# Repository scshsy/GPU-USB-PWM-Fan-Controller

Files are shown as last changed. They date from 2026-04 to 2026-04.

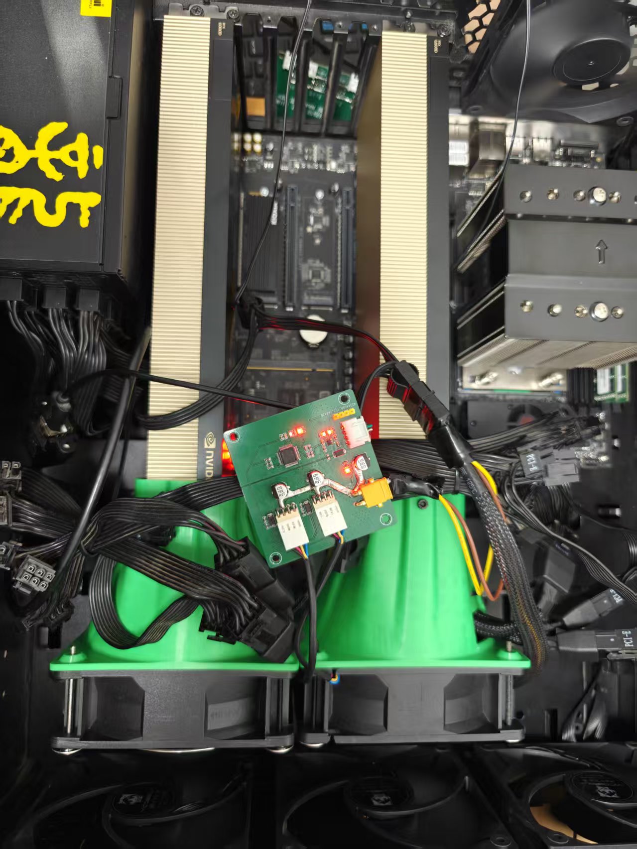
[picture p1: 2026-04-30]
RTX6000D散热方案/img3.jpg

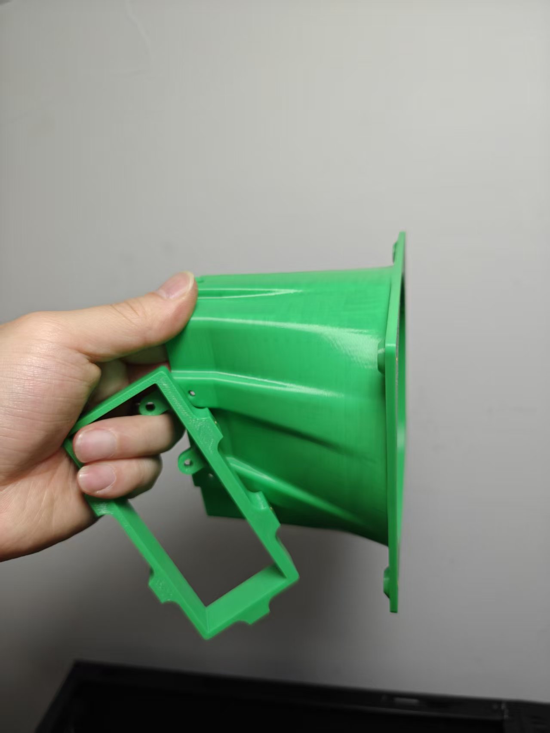
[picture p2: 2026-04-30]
RTX6000D散热方案/img.jpg

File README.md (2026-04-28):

# GPU USB PWM Fan Controller（GPU 温控 USB PWM 风扇控制器）

> **简易版（上手用这一页）**。详细版请看 `docs/PROJECT_GUIDE.md`。

## 项目做什么

- STM32G0B1 固件控制 **2 路 4-pin 风扇**：25 kHz PWM 调速 + TACH 测速
- USB CDC（虚拟串口）文本协议：主机下发占空比、回读 RPM、查询状态
- **Fail-safe 安全策略**：USB 未枚举 / 主机失联 / 脚本崩溃 → 自动回安全档
- PC 端脚本：读取 `nvidia-smi` 的 **多卡温度**，取最高温 → 计算 duty → 下发 → 回读 RPM

## 快速开始（Windows / 开发机）

### 1) 编译

```bash
pio run -e nucleo_g0b1re
```

产物：`.pio/build/nucleo_g0b1re/firmware.bin`

### 2) 一键 DFU 刷写（板子在跑应用时）

```bash
python tools/dfu_upload.py .pio/build/nucleo_g0b1re/firmware.bin
```

> dfu-util 的 exit code 74 已在脚本中兼容（STM32 ROM `:leave` 已知“假错误”）。

### 3) 串口验证（协议）

```bash
pio device monitor -b 115200
```

在 monitor 里输入：

- `get status`：看当前 duty/rpm/usb/src/wd/fault
- `get rpm`：看两路 RPM
- `set fan 1 30` + `set fan 2 30`：下发 duty
- `kick`：喂主机 watchdog（不改变 duty）
- `dfu`：进入 ROM DFU（供 `dfu_upload.py` 使用）

## 自动温控（GPU 温度→风速）

### 1) 运行（真实下发）

```bash
python tools/fan_daemon.py --port COM4
```

### 2) 配置文件（温度→duty 曲线）

默认读取：`/etc/pwm_fan/config`（Ubuntu/Linux；手动运行与 systemd 共用同一份）

配置样例见：`docs/PROJECT_GUIDE.md`（推荐用 `[curve] points = 40:30, 55:50, ...` 这种分段线性点）

### 3) 只演算不下发（dry-run）

```bash
python tools/fan_daemon.py --dry-run
```

## Ubuntu Server 一键部署（无需源码）

```bash
curl -fsSL https://raw.githubusercontent.com/scshsy/GPU-USB-PWM-Fan-Controller/main/tools/deploy.sh | sudo bash
```

脚本会自动：安装系统依赖 → 从 GitHub 拉取代码 → 安装程序和配置文件 → 启动 systemd 服务。

已有源码时也可手动执行：
```bash
sudo bash tools/deploy.sh
```

常用命令：
```bash
sudo systemctl status pwm-fan.service
sudo journalctl -u pwm-fan -f
pwm-fan-rpm
pwm-fan-status
pwm-fan-help
```

系统命令：
- `pwm-fan-rpm`
- `pwm-fan-status`
- `pwm-fan-help`

## 硬件源文件（开源入口）

- 嘉立创EDA 专业版工程（**原理图 + PCB**）：`hardware/GPU USB PWM Fan Controller.epro`

## 关键文档入口

- USB CDC（详细踩坑/架构）：`docs/USB_CDC_GUIDE.md`
- USB DFU（一页纸）：`docs/USB_DFU.md`
- USB DFU（详细版）：`docs/USB_DFU_GUIDE.md`
- 风扇控制（协议/安全策略/接线）：`docs/FAN_CONTROL.md`
- 项目总文档（详细版）：`docs/PROJECT_GUIDE.md`

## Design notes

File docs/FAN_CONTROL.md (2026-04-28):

# 风扇控制（GPU USB PWM Fan Controller）

## 1. 硬件接线与约束

### 1.1 4-pin 风扇线序（常见配色）

> 不同厂商可能配色不同，但行业常见是：

- 黑：GND
- 黄：+12V
- 绿：PWM（控制输入，25 kHz）
- 蓝：TACH（转速输出，开漏/开集电极）

### 1.2 本控制板 IO（已定板）

- **硬件源文件（嘉立创EDA 专业版，原理图 + PCB）**
  - `hardware/GPU USB PWM Fan Controller.epro`

- **PWM 输出（推挽，25 kHz）**
  - PA8 → TIM1_CH1 → FAN1_PWM
  - PA9 → TIM1_CH2 → FAN2_PWM
- **TACH 输入（外部 4.7K 上拉到 3.3V + RC 滤波 → MCU 浮空输入）**
  - PA6 → TIM3_CH1 → FAN1_TACH
  - PA7 → TIM3_CH2 → FAN2_TACH
- **风扇脉冲规格**
  - 每转 2 个脉冲（2 PPR）

### 1.3 供电说明（重要）

- **USB 与风扇 12V 供电无关**：风扇的 +12V 由外部 12V 电源提供。
- **必须共地**：外部 12V 电源的 GND 与本板 GND 必须相连（共地），否则 PWM/TACH 参考电平漂移会导致失控或测速异常。

---

## 2. CDC 文本协议（行协议）

### 2.1 基本规则

- 传输通道：USB CDC 虚拟串口（VID `0483` PID `5740`）
- 行结束：`\r\n` 或 `\n`
- 命令大小写不敏感
- 应答一行一条，末尾带 `\r\n`

### 2.2 命令表

| 命令 | 应答 | 说明 |
|---|---|---|
| `set fan <ch> <pct>` | `ok` / `err <reason>` | `ch` ∈ {1,2}，`pct` ∈ [0,100]；合法命令会刷新 host watchdog |
| `kick` | `ok` | 仅喂狗，不改变 duty |
| `get rpm` | `rpm 1=<n> 2=<m>` | 返回两路 RPM（停转/超时视为 0） |
| `get status` | `duty=<a>,<b> rpm=<n>,<m> usb=<0/1> src=<host|safe|default|override> wd=<ms_left> fault=0x<bits>` | 综合状态 |
| `?` |（CRS 诊断行）| 见 `docs/USB_CDC_GUIDE.md` |
| `dfu` | `entering DFU` 后复位 | 进入 ROM DFU（见 `docs/USB_DFU.md`） |

> `fault` bit（当前实现）：
> - bit0: USB 未枚举（非 CONFIGURED）
> - bit1: host watchdog 超时

---

## 3. 固件安全策略（Fail-safe）

### 3.1 两个常量（已分离）

- **上电默认档**：`FAN_DEFAULT_DUTY_PCT = 80%`
- **安全档**：`FAN_SAFE_DUTY_PCT = 80%`

未来可以独立调这两个值（例如默认 80%，失联档 100%）。

### 3.2 触发条件

1. **上电/复位**：先进入默认档（80%）
2. **USB 未枚举**：强制安全档（80%）
3. **主机失联 watchdog**：任意合法 `set fan` / `kick` 会刷新时间戳；超过 3000ms 未刷新 → 强制安全档（80%）

### 3.3 状态机（ASCII）

```
                +------------------+
   reset/power  |     DEFAULT      |
   ------------>+ duty=DEFAULT(80) |
                +------------------+
                        |
                        | (USB configured) + first host msg
                        v
                +------------------+
                |       HOST       |
                | duty=host target |
                +------------------+
                   |          |
     wd timeout     |          | USB not configured
  (>3000ms no kick) |          |
                   v          v
                +------------------+
                |       SAFE       |
                | duty=SAFE(80)    |
                +------------------+
                        ^
                        |
                        | (USB configured) + host msg resumes
                        |

  OVERRIDE：调试/应急覆盖（优先级最高），覆盖上面所有状态
```

---

## 4. PC 端温控脚本（`tools/fan_daemon.py`）

### 4.1 设计要点

- **多卡规则**：枚举所有 GPU，取温度最大值作为决策温度
- **双通道同步**：每轮都发 `set fan 1 X` + `set fan 2 X`
- **滞回**：3°C，避免频繁上下跳
- **最低保活档**：任何时候 duty < 30% 会被抬到 30%
- **失败兜底**：连续 3 次读不到温度时先改为 75%；再持续失败会退出，让板载 watchdog 接管安全档

### 4.2 用法

```bash
python tools/fan_daemon.py
```

常用参数：

```bash
python tools/fan_daemon.py --port COM5 --interval 1.0
python tools/fan_daemon.py --gpu-filter "RTX|A100" --curve preset:aggressive
python tools/fan_daemon.py --dry-run
```

---

## 5. 多卡日志样例（1/2/4 卡）

### 5.1 1 卡

```
2026-04-28 22:00:00 gpus=[0:52C] max=52C duty=44% rpm 1=12345 2=12340
```

### 5.2 2 卡（取最高温）

```
2026-04-28 22:00:01 gpus=[0:48C 1:76C] max=76C duty=90% rpm 1=17800 2=17720
```

### 5.3 4 卡（任意一张卡热就拉高风量）

```
2026-04-28 22:00:02 gpus=[0:41C 1:43C 2:44C 3:79C] max=79C duty=98% rpm 1=19500 2=19460
```

---

## 6. 调参方法与排错

### 6.1 先用 `get status` 看当前处于哪一档

示例：

```
duty=80,80 rpm=0,0 usb=0 src=safe wd=0 fault=0x1
```

判读：
- `usb=0`：未枚举（或已断开）
- `src=safe`：安全档生效
- `fault=0x1`：bit0=USB 未枚举

### 6.2 常见问题

- **插着 USB 但 `usb=0`**
  - 确认 PC 设备管理器已出现 CDC COM 口（VID:PID 0483:5740）
  - 确认数据线不是“仅充电线”
- **`get rpm` 始终 0**
  - 确认风扇 TACH 线接对
  - 确认外部 12V 与本板共地
  - 确认该风扇的 TACH 规格为 2 PPR（若不同需要改固件常量）

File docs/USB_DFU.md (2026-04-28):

# USB DFU 升级 - 快速指南

> 一页纸版本。详细原理 / 完整排错 / 实现细节请看 [USB_DFU_GUIDE.md](USB_DFU_GUIDE.md)

## 日常一键升级

```powershell
pio run
python tools\dfu_upload.py .pio\build\nucleo_g0b1re\firmware.bin
```

脚本自动完成：找串口 → 发 `dfu` 命令 → 等设备重枚举为 DFU → `dfu-util` 烧录 → 跳回应用。

**全程零手动**：不按按钮、不拔插 USB、不用 STLink。

---

## 首次配置（每台 PC 一次）

### Windows

```powershell
# 1) 装 scoop（已有可跳过）
Set-ExecutionPolicy -ExecutionPolicy RemoteSigned -Scope CurrentUser
irm get.scoop.sh | iex

# 2) 装命令行工具
scoop install dfu-util python
pip install pyserial

# 3) STLink 烧一次本工程的固件（最后一次用 STLink）
pio run -t upload
```

之后做一次 Zadig 驱动绑定（只一次）：

1. 打开串口（任意工具，如 `pio device monitor`），输入 `dfu` 回车
2. 设备会消失重枚举为 `STM32 BOOTLOADER`（PID:DF11）
3. 下载 [Zadig](https://zadig.akeo.ie/)，`Options → List All Devices`
4. 选 **STM32 BOOTLOADER**（USB ID 必须是 `0483 DF11`）→ 目标驱动选 **WinUSB** → `Replace Driver`

> ⚠ 千万**不要**选成 `USB 串行设备 / Virtual COM Port`（PID:5740），那个是 CDC，已经有正确的内置驱动。

完成后日常只需第一段那两行命令。

### Linux

```bash
sudo apt install dfu-util python3-pip
pip install pyserial

# udev 规则（一次性）
sudo tee /etc/udev/rules.d/99-stm32-dfu.rules <<'EOF'
SUBSYSTEMS=="usb", ATTRS{idVendor}=="0483", ATTRS{idProduct}=="df11", MODE="0666"
EOF
sudo udevadm control --reload-rules && sudo udevadm trigger
```

### macOS

```bash
brew install dfu-util python
pip install pyserial
```

---

## 万一砖了

```powershell
pio run -t upload
```

STLink 直刷永远是兜底。ROM bootloader 在 ROM 区不可写，应用层从不动 option byte，物理上不可能变真砖。

---

## 三句话原理速记

1. 应用收到 `dfu\r\n` → 写 magic 到 `TAMP->BKP0R` → `NVIC_SystemReset()`
2. 复位后 `main()` 第一行检测 magic → 跳 `0x1FFF0000`（ROM USB DFU bootloader）
3. PC 用 `dfu-util ... :leave` 烧 + 让 ROM 跳回 `0x08000000` 应用

代码：[`src/dfu.c`](../src/dfu.c)（约 130 行）
脚本：[`tools/dfu_upload.py`](../tools/dfu_upload.py)

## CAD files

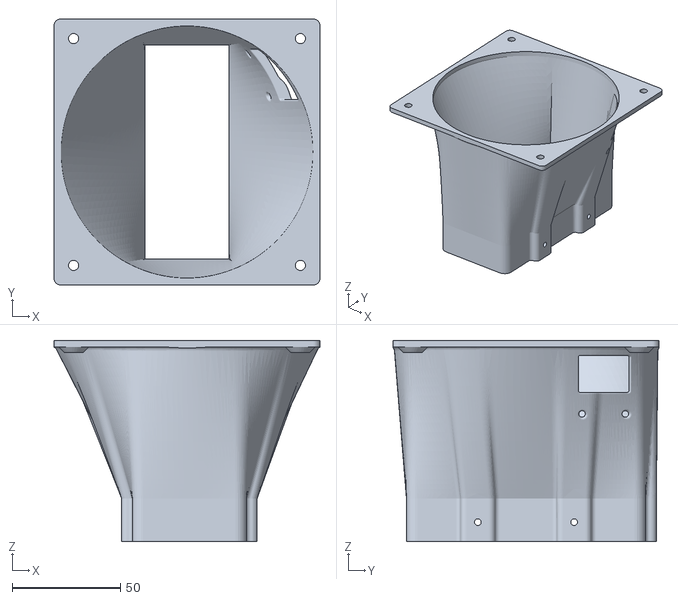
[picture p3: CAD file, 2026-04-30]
RTX6000D散热方案/导风罩打印件/rtx6000d风扇_单_参数化_高70_喇叭.stl
122.9 x 122.9 x 93.0

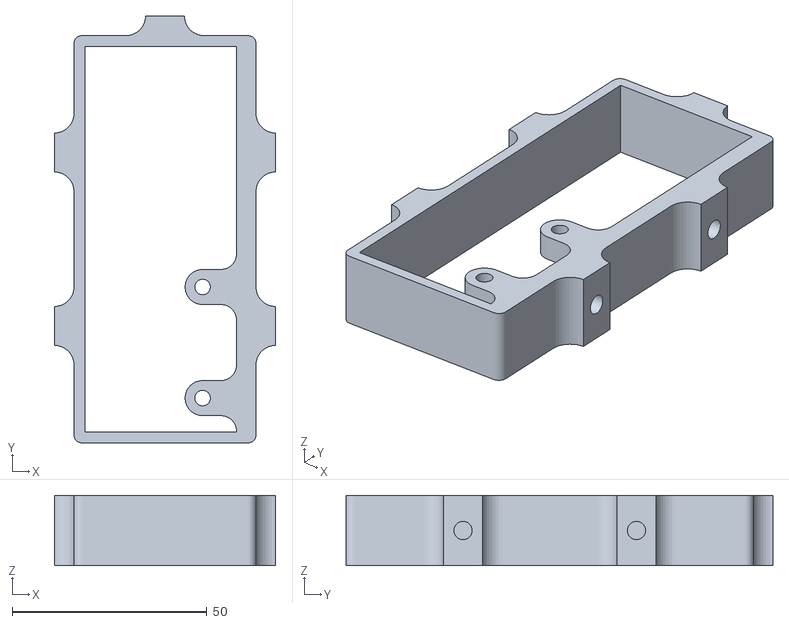
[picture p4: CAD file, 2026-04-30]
RTX6000D散热方案/导风罩打印件/rtx6000d风扇_单_参数化_高70_固定在风扇上.stl
56.7 x 109.5 x 18.0

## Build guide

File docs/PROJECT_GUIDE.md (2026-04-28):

# 项目文档（详细版）- GPU USB PWM Fan Controller（GPU 温控 USB PWM 风扇控制器）

> 本文是“详细版”。一页纸简易版见仓库根目录 `README.md`。

## 1. 总体架构

### 1.1 数据流

```
Host (Python)
  ├─ nvidia-smi 读 GPU 温度（多卡取 max）
  ├─ 温控曲线 + 滞回 => duty(%)
  └─ CDC 文本协议下发：
       set fan 1 <duty>
       set fan 2 <duty>
       get rpm
         ▲
         │
STM32G0B1 (Firmware)
  ├─ USB CDC RX -> CLI 行解析 -> fanctl 命令处理
  ├─ fanctl 安全仲裁 -> pwm 写 TIM1 CCR
  └─ tach 从 TIM3 输入捕获计算 RPM -> get rpm/status 回传
```

### 1.2 固件状态机（安全策略）

- **DEFAULT**：上电/复位默认 duty（`FAN_DEFAULT_DUTY_PCT`）
- **HOST**：USB 已枚举 + 主机 watchdog 未超时 → 使用 host 下发 duty
- **SAFE**：USB 未枚举 或 主机 watchdog 超时 → 强制 `FAN_SAFE_DUTY_PCT`
- **OVERRIDE**：调试覆盖（优先级最高）

详见：`docs/FAN_CONTROL.md`。

---

## 2. 目录与模块

### 2.1 固件（`src/`）

- `src/pwm.{c,h}`：TIM1 CH1/CH2 25kHz PWM（PA8/PA9）
- `src/tach.{c,h}`：TIM3 输入捕获 TACH（PA6/PA7，4 点平均，>1s 无脉冲=0）
- `src/fanctl.{c,h}`：仲裁、安全策略、命令处理（set/get/kick/status）
- `src/cli.{c,h}`：CDC 上的行协议框架（handler 注册、echo 兜底）
- `src/dfu.{c,h}`：`dfu` 命令 + magic + 跳 ROM bootloader
- `src/usb/*`：USB CDC 设备栈 glue

### 2.2 工具（`tools/`）

- `tools/dfu_upload.py`：一键 DFU（CDC 触发 → ROM DFU → dfu-util 烧录）
- `tools/fan_daemon.py`：GPU 温控守护（读温度 → 算 duty → 下发 → 回读 RPM）
- `tools/pwm_fan_cli.py`：一条命令做一次查询/设置（rpm/status/set/kick）
- `tools/install.sh`：Ubuntu Server 安装 systemd 服务 + 系统命令（幂等）

### 2.3 硬件（`hardware/`）

- `hardware/GPU USB PWM Fan Controller.epro`：嘉立创EDA 专业版工程（**原理图 + PCB**）

---

## 3. 固件协议（CDC 文本）

行结束：`\r\n` 或 `\n`，命令大小写不敏感。

常用命令：
- `set fan <1|2> <0..100>`
- `kick`
- `get rpm`
- `get status`
- `dfu`
- `?`（CRS 诊断）

协议与安全策略详见：`docs/FAN_CONTROL.md`。

---

## 4. 编译 / 刷写 / 串口验证

### 4.1 编译

```bash
pio run -e nucleo_g0b1re
```

### 4.2 一键 DFU 刷写（推荐）

```bash
python tools/dfu_upload.py .pio/build/nucleo_g0b1re/firmware.bin
```

### 4.3 串口 monitor 验证

```bash
pio device monitor -b 115200
```

建议验证顺序：
1) `get status`
2) `get rpm`
3) `set fan 1 30` + `set fan 2 30`
4) `get status` 确认 `src=host duty=30,30`
5) 停止发送任何命令 > 3s，再 `get status`，应回 `src=safe duty=80,80`

---

## 5. PC 温控脚本（`tools/fan_daemon.py`）

### 5.1 核心规则（必须记住）

- **多卡取最高温**：决策温度 = `max(所有命中 GPU 的温度)`
- **双通道同步**：每轮必发 `set fan 1 X` 与 `set fan 2 X`
- **主机 watchdog**：每轮 `set fan` 本身就会“喂狗”（保持 `src=host`）
- **异常兜底**：脚本异常退出 → 板子 3s 后自动回 SAFE（80%）

### 5.2 dry-run 是什么

`--dry-run` 表示“只演算不下发”：会读温度、算 duty、打日志，但不会打开串口，也不会读取 RPM。

### 5.3 配置文件（推荐）

默认配置路径：`/etc/pwm_fan/config`（Ubuntu/Linux；手动运行与 systemd 共用同一份）

也可用 `--config` 指定其他路径。

示例（带注释）：

```ini
[general]
interval = 1.0
gpu_filter =
curve = preset:balanced
hysteresis_c = 3.0
min_duty = 30
max_fail = 10
temp_fail_duty = 75

[curve]
; points = temp:duty, temp:duty, ...
points = 40:30, 55:50, 70:75, 80:100
```

说明：
- 若提供了 `[curve] points`，则 **points 优先于 preset**
- points 是分段线性插值：温度在两点之间按比例插值；超出范围按端点夹紧

---

## 6. Ubuntu Server 部署（systemd 常驻）

### 6.1 安装（幂等，可重复执行）

```bash
sudo bash tools/install.sh
```

安装后：
- 服务：`pwm-fan.service`
- 配置：`/etc/pwm_fan/config`
- 日志（推荐）：`journalctl -u pwm-fan -f`
- 系统命令：
  - `pwm-fan-rpm`
  - `pwm-fan-status`
  - `pwm-fan-help`

### 6.2 修改配置后生效

```bash
sudo systemctl restart pwm-fan.service
```

---

## 7. WSL2 测试（USB 透传）

WSL2 默认看不到 Windows COM，需要 `usbipd-win` attach。

Windows（管理员 PowerShell）：

```powershell
usbipd list
usbipd bind --busid <BUSID>
usbipd attach --wsl --busid <BUSID>
```

WSL2：

```bash
ls -l /dev/ttyACM* /dev/ttyUSB* 2>/dev/null
python3 tools/pwm_fan_cli.py --port /dev/ttyACM0 status
```

---

## 8. 常见问题排错（最短路径）

- **刷完 DFU 后 CDC 不回来**
  - 先等 2~3 秒（Windows 枚举有时慢）
  - 仍不行 → `pio run -t upload` 走 STLink 救砖
- **`get rpm` 始终 0**
  - 确认 TACH 线接对、外部 12V 与板子共地
  - 确认风扇是 2 PPR（若不同需改固件常量）
- **脚本跑着跑着进入 SAFE**
  - 看 `get status` 的 `wd=` 是否归零、`fault` bit1 是否置位
  - 检查主机脚本是否卡死/串口是否被别的程序占用

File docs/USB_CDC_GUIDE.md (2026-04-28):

# STM32G0B1 USB CDC 实战指南

> 风扇控制板的 CDC 文本协议与安全策略见：`prompt.txt` 的 “§A 固件侧”。

> 目标读者：未来回头维护这份代码的你 / 接手项目的同事 / 在别的板子上复用这套
> USB CDC 方案的人。
>
> 写在前面：这一份文档不是"USB 协议教科书"，而是把这一次实现 USB CDC 时
> **踩过的所有坑**和**最终成功的工程套路**都记下来，下一次遇到同类问题能直接
> 跳过陷阱。文档与代码 1:1 对齐，所有正面示例都来自当前 `src/` 与 `src/usb/`，
> 反面示例标注 ❌，正面示例标注 ✔。
>
> 适用对象：STM32G0B1CBT6（USB_DRD_FS，单机 Device 模式，全速 12 Mbit/s，HSI48）
> 在其他系列（F0/F4/G4/H7）上 **大部分思路通用**，但 PCD/MSP 细节不同，注意
> 区分。

---

## 目录

1. [一句话总结](#一句话总结)
2. [硬件前提与电气](#硬件前提与电气)
3. [软件架构总览](#软件架构总览)
4. [时钟方案：HSI16 + HSI48(USB) + CRS](#时钟方案hsi16--hsi48usb--crs)
5. [中断与并发模型](#中断与并发模型)
6. [PMA 内存布局](#pma-内存布局)
7. [RX/TX 数据通路](#rxtx-数据通路)
8. [描述符与 VID/PID](#描述符与-vidpid)
9. [PlatformIO 工程配置](#platformio-工程配置)
10. [踩坑大全（反面示例）](#踩坑大全反面示例)
11. [调试方法论：LED 打卡 + 二分法](#调试方法论led-打卡--二分法)
12. [上线测试 Checklist](#上线测试-checklist)
13. [常见问题速查](#常见问题速查)
14. [参考资料](#参考资料)

---

## 一句话总结

**STM32G0 系列上，USB CDC 想跑起来必须做对这三件事，缺一不可：**

1. ✅ **HSI48 + CRS 用 USB SOF 自动校准**（USB FS 协议要求时钟精度 ±0.25%，HSI48 出厂仅 ±1%~±2%）
2. ✅ **`HAL_PCD_MspInit` 里必须 `__HAL_RCC_SYSCFG_CLK_ENABLE`**（G0 把 USB/UCPD1/UCPD2 三个中断挂在同一根 IRQn，HAL ISR 入口要读 `SYSCFG->IT_LINE_SR[8]` 辨认；SYSCFG 没时钟 → 寄存器读 0 → ISR 立刻 return → ISTR 标志没清 → 反复触发 → 主循环饿死）
3. ✅ **中断里只搬数据、TX 永不死等**（不阻塞 ISR、不阻塞主循环，是"USB 通信卡死/无限重启"类问题的根治方案）

第 2 点是这次最大的坑，也是 STM32G0 USB 区别于 F4/G4 的特有陷阱。详见
[反面示例 11.1](#111-syscfg-时钟未开-本工程最大坑)。

---

## 硬件前提与电气

### 必备

| 项 | 值 | 说明 |
|---|---|---|
| MCU | STM32G0B1CBT6 | 内置 USB FS 外设（USB_DRD_FS），含 PMA SRAM 2KB |
| USB DP | PA12 | 专用引脚，**不要**当 GPIO 配置 |
| USB DM | PA11 | 同上 |
| USB VBUS | VDD | 本工程为自供电（STLink 或独立电源），不需要 VBUS 检测 |
| 时钟源 | 内部 HSI48 + CRS | **不需要外部晶振**（这是 G0 USB 相比 F1/F4 的一大优点） |

### 常见误判

- ❌ "USB 必须接外部 12/24 MHz 晶振" → **错**。G0 内置 HSI48，配合 CRS 用 USB SOF 自动校准，比外部晶振更省 BOM。
- ❌ "DP 线上需要外接 1.5kΩ 上拉电阻到 +3.3V 才能让主机识别为全速设备" → **错**。STM32G0 内置可控制的 1.5kΩ DP 上拉，由 `USB_BCDR.DPPU` 位控制；HAL 在 `HAL_PCD_Start()` 内会调 `USB_DevConnect()` 自动拉高。**额外的外部上拉只会让信号完整性变差**。
- ❌ "USB 数据线要串 22~33Ω 阻抗匹配电阻" → 在 PCB 阻抗严格控制（90Ω 差分）的板子上是好做法；在原型板上 0Ω 直连也能跑，**但布线长度别超过 10cm，且尽量等长**。

### USB 数据线 vs ST-Link 供电线

调试时一个常见混淆：板子用 ST-Link 供电时，**ST-Link 那条 USB 是接到电脑的，但电脑看到的是 ST-Link 自己**，跟 MCU 上的 PA11/PA12 USB **完全无关**。

要让 PC 识别 MCU 上的 CDC 设备，必须用**第二根独立 USB 线**接到板上 MCU 那个 USB 接口（一般是 USB-C 或 Micro-USB）。

---

## 软件架构总览

```
src/
├── main.c                 ← 应用入口、时钟配置、主循环 echo + LED + CRS 诊断
├── stm32g0xx_it.c         ← 核心异常 + USB IRQ → HAL_PCD_IRQHandler
└── usb/
    ├── usb_device.c/.h    ← MX_USB_Device_Init（USBD_Init/RegisterClass/Start）
    ├── usbd_conf.c/.h     ← PCD ↔ USBD_LL 桥接 + MSP 时钟/NVIC + PMA 布局 + 静态内存池
    ├── usbd_desc.c/.h     ← USB 描述符（设备/字符串/序列号）
    └── usbd_cdc_if.c/.h   ← CDC 应用层（RX 环形缓冲、非阻塞 TX、LineCoding）

lib/STM32_USB_Device/      ← ST 官方 USB Device Library（usbd_core/cdc/ctlreq/ioreq）
```

### 分层职责

```
┌───────────────────────────────────────────────────────┐
│  应用层  main.c                                       │
│   ├── HAL_GetTick 心跳调度                            │
│   ├── CDC_RingPop（消费 RX 环形缓冲）                 │
│   ├── CDC_Transmit_NonBlocking（非阻塞 TX）           │
│   └── update_led_usb / crs_poll / handle_query        │
├───────────────────────────────────────────────────────┤
│  CDC 接口层  usbd_cdc_if.c                            │
│   ├── CDC_Init/DeInit/Control/Receive/TransmitCplt    │
│   ├── RX 环形缓冲（256B）+ 溢出计数                   │
│   ├── LineCoding 7B 副本                              │
│   └── 中断绝不做业务 / TX 绝不死等                    │
├───────────────────────────────────────────────────────┤
│  USB Device 框架层  STM32_USB_Device + usb_device.c   │
│   ├── USBD_Init / USBD_RegisterClass(USBD_CDC)        │
│   ├── USBD_CDC_RegisterInterface(&USBD_Interface_fops)│
│   └── USBD_Start                                      │
├───────────────────────────────────────────────────────┤
│  低层桥接  usbd_conf.c                                │
│   ├── USBD_LL_*  → HAL_PCD_*                          │
│   ├── HAL_PCD_*Callback → USBD_LL_*                   │
│   ├── PMA 布局静态规划                                │
│   ├── HAL_PCD_MspInit：SYSCFG/USB CLK + NVIC          │
│   └── 静态内存池替代 malloc                           │
├───────────────────────────────────────────────────────┤
│  HAL/LL  stm32g0xx_hal_pcd.c + stm32g0xx_ll_usb.c     │
│  外设  USB_DRD_FS + PMA SRAM 2KB                      │
└───────────────────────────────────────────────────────┘
```

**唯一的回调链方向**：

- 主循环 → CDC_Transmit_NonBlocking → USBD_CDC_TransmitPacket → HAL_PCD_EP_Transmit → 写寄存器
- 硬件 IRQ → HAL_PCD_IRQHandler → HAL_PCD_*Callback → USBD_LL_* → CDC_Receive_FS / CDC_TransmitCplt_FS → 写环形缓冲
- 应用层从不主动调 HAL_PCD_*；HAL_PCD_*Callback 也从不主动调应用层

---

## 时钟方案：HSI16 + HSI48(USB) + CRS

### 设计理由

- **SYSCLK 用 HSI16（16MHz）**：G0 上 HSI48 **不能**作为 SYSCLK，只能给 USB；用 HSI16 简单稳定，FLASH 0WS，足够 LED + USB 业务。如果你确实要 64MHz，请用 PLL HSI16×4，但要注意 FLASH WS=2、CRS 仍走 HSI48 独立路径。
- **USBCLK 用 HSI48**：内置高精度 RC 振荡器，48MHz，给 USB 外设作为 48MHz 参考时钟。
- **CRS 用 USB SOF 同步**：USB 主机每 1ms 发一次 SOF（Start-Of-Frame）帧，CRS 把这个 1kHz 信号当 reference 来连续微调 HSI48 的 TRIM 值，把它实际频率拉到 ±50 ppm 以内（远小于 USB FS 要求的 ±2500 ppm）。

### 配置代码（main.c::SystemClock_Config）

```c
/* 1) 同时启用 HSI 和 HSI48 */
RCC_OscInitStruct.OscillatorType      = RCC_OSCILLATORTYPE_HSI | RCC_OSCILLATORTYPE_HSI48;
RCC_OscInitStruct.HSIState            = RCC_HSI_ON;
RCC_OscInitStruct.HSIDiv              = RCC_HSI_DIV1;
RCC_OscInitStruct.HSI48State          = RCC_HSI48_ON;
RCC_OscInitStruct.PLL.PLLState        = RCC_PLL_NONE;
HAL_RCC_OscConfig(&RCC_OscInitStruct);

/* 2) SYSCLK = HSI16，0 WS */
RCC_ClkInitStruct.SYSCLKSource   = RCC_SYSCLKSOURCE_HSI;
RCC_ClkInitStruct.AHBCLKDivider  = RCC_SYSCLK_DIV1;
RCC_ClkInitStruct.APB1CLKDivider = RCC_HCLK_DIV1;
HAL_RCC_ClockConfig(&RCC_ClkInitStruct, FLASH_LATENCY_0);

/* 3) USB 外设时钟源 = HSI48 */
PeriphClkInit.PeriphClockSelection = RCC_PERIPHCLK_USB;
PeriphClkInit.UsbClockSelection    = RCC_USBCLKSOURCE_HSI48;
HAL_RCCEx_PeriphCLKConfig(&PeriphClkInit);

/* 4) CRS：USB SOF 自动校 HSI48
 *    Reload=0xBB7F=47999 (即每帧 48000 个 HSI48 cycle - 1)
 *    Source=USB（专用同步源；G0 还支持 LSE/GPIO） */
__HAL_RCC_CRS_CLK_ENABLE();
RCC_CRSInitStruct.Prescaler             = RCC_CRS_SYNC_DIV1;
RCC_CRSInitStruct.Source                = RCC_CRS_SYNC_SOURCE_USB;
RCC_CRSInitStruct.Polarity              = RCC_CRS_SYNC_POLARITY_RISING;
RCC_CRSInitStruct.ReloadValue           = RCC_CRS_RELOADVALUE_DEFAULT;
RCC_CRSInitStruct.ErrorLimitValue       = RCC_CRS_ERRORLIMIT_DEFAULT;
RCC_CRSInitStruct.HSI48CalibrationValue = RCC_CRS_HSI48CALIBRATION_DEFAULT;
HAL_RCCEx_CRSConfig(&RCC_CRSInitStruct);
```

### 校准是否真的在工作？

代码里加了 `?` 命令：在串口里发 `?\n` 会回一行实时 CRS 状态：

```
CRS TRIM=0x40 SYNCOK=12345 ERR=0 MISS=0 OVF=0
```

判读：

| 字段 | 期望 | 含义 |
|---|---|---|
| `SYNCOK` | 持续 +1000/秒 | 每帧 SOF 都对上了 |
| `ERR` | 0 或个位数 | SYNC 输入与本地差超出 ErrorLimit |
| `MISS` | 0 或个位数 | 应到的 SOF 没到（拔线/挂起会增加） |
| `OVF` | **必须 0** | TRIM 跑到边界 → HSI48 严重偏离，要换源 |
| `TRIM` | 0x40±几 | HSI48 实时微调值，随温度小幅漂动 |

间接证据：**echo 顺畅、不掉包 = HSI48 实际偏差远 < 0.25%（USB FS 阈值）= CRS 一定在工作**。

---

## 中断与并发模型

### 优先级布置

| 中断 | NVIC 优先级 | 设置位置 |
|---|---|---|
| SysTick | 0（最高） | HAL_Init 内自动 |
| **USB_UCPD1_2_IRQn** | 2 | `usbd_conf.c::HAL_PCD_MspInit` |

**Cortex-M0+ 只有 4 级（0~3），数字越小越高**。USB 在 2 是为了**永远不阻塞 SysTick**（保证 `HAL_GetTick()` 准确，是非阻塞 TX 超时机制的基础）。

### 三段式数据流

```
   主机 USB 主控                   STM32G0
       ▼                              ▲
  发 OUT 包 ───→ USB 外设硬件 ───→ ISR (USB_UCPD1_2_IRQHandler)
                                      │
                                      ▼
                          HAL_PCD_DataOutStageCallback
                                      │
                                      ▼
                              USBD_LL_DataOutStage
                                      │
                                      ▼
                                CDC_Receive_FS（仍在 ISR 上下文）
                                      │
                                      ├── 把 *Buf 字节抄进 RX 环形缓冲
                                      ├── cdcEventFlag = 1（提示 LED）
                                      └── 立刻 USBD_CDC_ReceivePacket 重开下一帧
                                              ↑↑↑ 必须同步做，否则 NAK
   主循环（main 上下文）
       │
       ▼
   CDC_RingPop → 业务处理 → CDC_Transmit_NonBlocking → 寄存器写完返回
                                                          ↓
                                                    硬件发完 → ISR
                                                          ↓
                                              CDC_TransmitCplt_FS
                                              (置 hcdc->TxState = 0)
```

### 三条铁律

1. **ISR 内只搬数据，不解析、不发送、不调任何阻塞 API**（`HAL_Delay`、`while (busy)`、`printf` 全禁）。
2. **TX 永不死等**：`CDC_Transmit_NonBlocking` 在 `dev_state != CONFIGURED` 或 `hcdc->TxState != 0` 时立刻返回 `USBD_BUSY`，由调用方决定重试或丢弃。
3. **共享变量加 `volatile`**：`rxRing`/`rxHead`/`rxTail`/`rxOverflowCnt`/`cdcEventFlag` 都被 ISR 与主循环共享，必须 `volatile` 防止编译器优化掉。`rxHead`/`rxTail` 用 16 位单字读写，单核 M0+ 上单字读写即原子，无需锁。

---

## PMA 内存布局

USB_DRD_FS 自带 2KB 的 Packet Memory Area (PMA)，CPU 通过专用总线访问。**所有 EP 缓冲、BTABLE 都必须放在 PMA 内，且互不重叠**。

本工程在 `usbd_conf.c::USBD_LL_Init` 里**手动**规划：

```
PMA 偏移   长度    用途
0x00      0x40   BTABLE   (8 EP × 8B)
0x40      0x40   EP0 OUT  (control, 64B)
0x80      0x40   EP0 IN   (control, 64B)
0xC0      0x40   EP1 IN   (CDC bulk in, 64B)
0x100     0x40   EP1 OUT  (CDC bulk out, 64B)
0x140     0x08   EP2 IN   (CDC interrupt notify, 8B)
─────────────
共占 328B，PMA 还剩 1720B 余量
```

```c
HAL_PCDEx_PMAConfig(&hpcd_USB_DRD_FS, 0x00U, PCD_SNG_BUF, 0x40U);   /* EP0 OUT */
HAL_PCDEx_PMAConfig(&hpcd_USB_DRD_FS, 0x80U, PCD_SNG_BUF, 0x80U);   /* EP0 IN  */
HAL_PCDEx_PMAConfig(&hpcd_USB_DRD_FS, 0x81U, PCD_SNG_BUF, 0xC0U);   /* EP1 IN  */
HAL_PCDEx_PMAConfig(&hpcd_USB_DRD_FS, 0x01U, PCD_SNG_BUF, 0x100U);  /* EP1 OUT */
HAL_PCDEx_PMAConfig(&hpcd_USB_DRD_FS, 0x82U, PCD_SNG_BUF, 0x140U);  /* EP2 IN  */
```

`HAL_PCDEx_PMAConfig` 第二个参数是 EP 地址（bit7=方向：0=OUT/1=IN），第四个参数是 PMA 偏移量（字节）。

### 核对清单

- [ ] BTABLE 大小 = `dev_endpoints × 8`（hpcd.Init.dev_endpoints=8 → BTABLE=64B）
- [ ] 所有 EP 缓冲不与 BTABLE 重叠
- [ ] 所有 EP 缓冲互不重叠
- [ ] 偏移地址必须是奇数地址不可用（HW 要求 word 对齐，最好按 16/32/64 对齐）
- [ ] 总占用 ≤ 2048B

---

## RX/TX 数据通路

### RX 路径（usbd_cdc_if.c）

```c
static int8_t CDC_Receive_FS(uint8_t *Buf, uint32_t *Len)
{
    /* 1. 把 Buf[0..*Len) 抄进环形缓冲，环满则 rxOverflowCnt++ */
    for (uint32_t i = 0; i < *Len; i++) {
        uint16_t next = (rxHead + 1U) % RX_RING_SIZE;
        if (next == rxTail) { rxOverflowCnt++; break; }
        rxRing[rxHead] = Buf[i];
        rxHead = next;
    }
    cdcEventFlag = 1U;

    /* 2. 立刻重开下一帧（关键！否则之后所有包 NAK） */
    USBD_CDC_SetRxBuffer(&hUsbDeviceFS, UserRxBufferFS);
    USBD_CDC_ReceivePacket(&hUsbDeviceFS);
    return USBD_OK;
}
```

主循环：

```c
uint8_t b;
while (CDC_RingPop(&b)) {
    /* ... 业务处理（行解析、命令分发） ... */
}
```

### TX 路径

```c
uint8_t CDC_Transmit_NonBlocking(uint8_t *buf, uint16_t len)
{
    if (hUsbDeviceFS.dev_state != USBD_STATE_CONFIGURED) return USBD_BUSY;

    USBD_CDC_HandleTypeDef *hcdc =
        (USBD_CDC_HandleTypeDef *)hUsbDeviceFS.pClassData;
    if (hcdc == NULL || hcdc->TxState != 0U) return USBD_BUSY;

    USBD_CDC_SetTxBuffer(&hUsbDeviceFS, buf, len);
    return USBD_CDC_TransmitPacket(&hUsbDeviceFS);   /* 立刻返回 */
}
```

主循环按行 echo 时的安全发送：

```c
/* 软件级有限重试：最多等 5 ms 让 TX 空闲，超时就丢 */
uint32_t deadline = HAL_GetTick() + 5U;
while (CDC_Transmit_NonBlocking(lineBuf, lineLen) == USBD_BUSY) {
    if ((int32_t)(HAL_GetTick() - deadline) >= 0) break;
}
```

**为什么有这个 5ms 上限？** 因为 `USBD_BUSY` 多半是上一包还没发完。USB FS 一帧 1ms，5ms 内绝大多数情况下能空出来。如果还忙 → 主机端有问题（比如阻塞读不消费），主循环不能为此卡死。

---

## 描述符与 VID/PID

```c
#define USBD_VID  0x0483   /* ST */
#define USBD_PID  0x5740   /* "STM32 Virtual COM Port" */
```

**为什么沿用 ST 默认？**

- Linux 内核 `cdc_acm` 模块、Windows 10/11 的 `usbser.sys` 都自带这对 VID/PID 的免驱列表
- 设备插上无需安装驱动，直接出现 `/dev/ttyACM0` 或 `COMx`

如果做商用产品，**必须申请自己的 VID**（USB-IF 收 6000 美元/年）；个人/原型阶段可以用 `pid.codes` 提供的免费 PID 命名空间。

### 序列号生成

`usbd_desc.c::USBD_FS_SerialStrDescriptor` 把 STM32 96-bit UID 转 24 字符 hex 串，确保不同板子的 COM 实例可区分（避免 Windows 串口号被同一 PID 的设备复用）。

---

## PlatformIO 工程配置

```ini
[env:nucleo_g0b1re]
platform = ststm32
board = nucleo_g0b1re
framework = stm32cube
board_build.mcu = stm32g0b1cbt6
board_build.flash_size = 128k

build_flags =
    -D USE_HAL_DRIVER
    -D STM32G0B1xx
    -D USBD_USE_CDC
    -I src/usb
    -I lib/STM32_USB_Device/include

; LDF：deep+ 让链接器递归扫描 USB 中间件库的依赖
lib_ldf_mode = deep+
; 不要把库打成 .a 归档，避免 USBD_LL_* 弱符号被剔除
lib_archive = no

upload_protocol = stlink
debug_tool = stlink
monitor_speed = 115200
```

### `lib_archive = no` 的必要性

ST USB Device Library 里 `USBD_LL_*` 系列函数有部分是 `__weak` 默认实现，我们在 `usbd_conf.c` 里提供了真正的实现。**默认 `lib_archive = yes` 会把库打成 `.a` 归档**，链接器只会从归档里"按需"取符号——这时弱符号优先于强符号被取走，导致我们写的 `USBD_LL_Init` 等永远不被调用，USB 启动后无任何枚举反应。

---

## 踩坑大全（反面示例）

按踩过的概率从高到低排，每条都给反面示例和正面写法。

---

### 11.1 ❌ SYSCFG 时钟未开（本工程最大坑）

**症状**：USB 中断启用后立即挂死。具体：USBD_Init/RegisterClass/Start 都返回成功，但 `USBD_Start` 一返回，主循环立刻被无尽中断打断；外部观察是"主循环完全饿死，LED 全黑"。

**根因**：

```c
/* stm32g0xx_hal_pcd.c::HAL_PCD_IRQHandler 入口 */
void HAL_PCD_IRQHandler(PCD_HandleTypeDef *hpcd)
{
  uint32_t wIstr = USB_ReadInterrupts(hpcd->Instance);

  /* G0 把 USB / UCPD1 / UCPD2 三个外设挂在同一个 IRQn=28 上，
   * 用 SYSCFG->IT_LINE_SR[8] 的 bit 来辨认是哪个外设触发 */
  if ((SYSCFG->IT_LINE_SR[8] & (0x1U << 2)) == 0U) {
    return;
  }
  /* ... 真正处理 ... */
}
```

**SYSCFG 时钟没开时，`SYSCFG->IT_LINE_SR[8]` 读取永远为 0** → HAL 误判"不是 USB 中断" → 立刻 `return` → 但是 `USB->ISTR` 标志没被清 → NVIC 立刻重新触发同一中断 → 主循环饿死。

❌ **错误**（漏配 SYSCFG）：

```c
void HAL_PCD_MspInit(PCD_HandleTypeDef *pcdHandle)
{
    if (pcdHandle->Instance == USB_DRD_FS) {
        __HAL_RCC_USB_CLK_ENABLE();   /* 只开 USB，没开 SYSCFG */
        HAL_NVIC_SetPriority(USB_UCPD1_2_IRQn, 2, 0);
        HAL_NVIC_EnableIRQ(USB_UCPD1_2_IRQn);
    }
}
```

✔ **正确**：

```c
void HAL_PCD_MspInit(PCD_HandleTypeDef *pcdHandle)
{
    if (pcdHandle->Instance == USB_DRD_FS) {
        __HAL_RCC_SYSCFG_CLK_ENABLE();   /* ⭐ G0 必须开 */
        __HAL_RCC_USB_CLK_ENABLE();
        HAL_NVIC_SetPriority(USB_UCPD1_2_IRQn, 2, 0);
        HAL_NVIC_EnableIRQ(USB_UCPD1_2_IRQn);
    }
}
```

**适用范围**：STM32G0 全系（共享 IRQn 设计）。F0/F4/G4/H7 的 PCD HAL 不读 SYSCFG，**没这个坑**。

---

### 11.2 ❌ HSI48 当 SYSCLK

❌ **错误**：

```c
RCC_ClkInitStruct.SYSCLKSource = RCC_SYSCLKSOURCE_HSI48;   /* 编译错或运行时挂 */
```

G0 上 HSI48 是给 USB 专用的时钟分支，**不可作 SYSCLK**。即使强行配，HAL 会拒绝并返回 `HAL_ERROR`。

✔ **正确**：SYSCLK 用 HSI16 或 PLL；USB 单独走 HSI48。

---

### 11.3 ❌ `lib_archive = yes` 导致 USBD_LL_* 弱符号被剔除

❌ **错误**：默认 `platformio.ini`，没显式关 `lib_archive`。

```
[env:xxx]
platform = ststm32
framework = stm32cube
; 默认 lib_archive = yes
```

链接结果：库里的 `__weak USBD_StatusTypeDef USBD_LL_Init(...) { return USBD_FAIL; }` 直接生效；我们写的强符号被链接器忽略。USB 永不枚举。

✔ **正确**：`lib_archive = no`。

---

### 11.4 ❌ 在 ISR 里做协议解析 / 调用阻塞 API

❌ **错误**：

```c
static int8_t CDC_Receive_FS(uint8_t *Buf, uint32_t *Len)
{
    if (Buf[0] == 'P' && Buf[1] == 'I' && Buf[2] == 'N' && Buf[3] == 'G') {
        char ack[] = "PONG\r\n";
        CDC_Transmit_NonBlocking((uint8_t*)ack, 6);   /* ⚠ 在 ISR 里发包！ */
        HAL_Delay(10);                                /* ⚠ ISR 里调 HAL_Delay */
    }
    /* ... */
}
```

后果：
1. ISR 里 `CDC_Transmit_NonBlocking` 可能正好遇到 TxState=1，自旋等待。
2. `HAL_Delay` 等 SysTick 推进；但 SysTick 优先级 = 0，USB IRQ 优先级 = 2，**SysTick 能抢占 USB IRQ**，但是如果 USB IRQ 仍在调 `HAL_Delay`，ISR 就被永久挂起 → 主循环及更高优先级中断都饿死。

✔ **正确**：ISR 只搬数据 + 重开 ReceivePacket，业务全推到主循环。

---

### 11.5 ❌ TX 死等

❌ **错误**：

```c
while (CDC_Transmit_NonBlocking(buf, len) == USBD_BUSY) { /* 死等 */ }
```

主机端不读、或主机断开但 `dev_state` 还没切到 SUSPENDED 时，这个循环可能永久停不下来。

✔ **正确**：超时上限。

```c
uint32_t deadline = HAL_GetTick() + 5U;
while (CDC_Transmit_NonBlocking(buf, len) == USBD_BUSY) {
    if ((int32_t)(HAL_GetTick() - deadline) >= 0) break;
}
```

---

### 11.6 ❌ 忘记重开 ReceivePacket

❌ **错误**：

```c
static int8_t CDC_Receive_FS(uint8_t *Buf, uint32_t *Len)
{
    /* ... 抄数据到环形缓冲 ... */
    return USBD_OK;   /* 忘了重开下一帧！ */
}
```

后果：第一包正常收，之后所有 OUT 包 NAK，主机重传 3 次后报错断开。

✔ **正确**：每次 Receive_FS 末尾必须 `USBD_CDC_ReceivePacket`。

---

### 11.7 ❌ 中断优先级反了（USB 比 SysTick 高）

❌ **错误**：

```c
HAL_NVIC_SetPriority(USB_UCPD1_2_IRQn, 0, 0);   /* USB 抢 SysTick！ */
/* HAL_Init 默认 SysTick 优先级 0 */
```

后果：`HAL_Delay`、超时机制依赖 SysTick；如果 USB ISR 高优先级 + 偶尔耗时（比如处理 SETUP 或 EP_Open），SysTick 会被挡，`HAL_GetTick()` 不动 → 主循环超时机制失效。

✔ **正确**：`HAL_NVIC_SetPriority(USB_UCPD1_2_IRQn, 2, 0)`，比 SysTick(0) 低。

---

### 11.8 ❌ 把 PA11/PA12 当 GPIO 配置

❌ **错误**：

```c
GPIO_InitStruct.Pin   = GPIO_PIN_11 | GPIO_PIN_12;
GPIO_InitStruct.Mode  = GPIO_MODE_AF_PP;
GPIO_InitStruct.Alternate = GPIO_AF0_USB;
HAL_GPIO_Init(GPIOA, &GPIO_InitStruct);   /* 多余 */
```

STM32G0 上 PA11/PA12 是 USB FS 的**专用引脚**，HAL_PCD_Init 内部会自动接到 USB PHY，**不走 GPIO 端口控制器**。多写没坏处但浪费代码；如果**配错 Mode**（比如 Output Push-Pull）会破坏 USB 信号。

✔ **正确**：完全不在 `MX_GPIO_Init` 里碰 PA11/PA12。

---

### 11.9 ❌ 外加 1.5kΩ DP 上拉电阻

❌ **错误**：原理图上 PA12 → 1.5kΩ → 3.3V。

STM32G0 内置软件可控 DP 上拉，由 `USB->BCDR.DPPU` 控制。HAL 在 `HAL_PCD_Start()` 内部自动拉高（通过 `USB_DevConnect`）。

外加上拉电阻的后果：
- 信号边沿被劣化，串扰增加
- 软断开（如 STOP 模式 USB 唤醒前要先 disconnect）失效
- 总线复位检测可能误触

✔ **正确**：直接 PA11/PA12 到 USB 接口（如有阻抗匹配需求可串 22~33Ω，但**不要**对地或对 VCC 加电阻）。

---

### 11.10 ❌ `hpcd.pData` / `pdev->pData` 没双向绑定

❌ **错误**：

```c
USBD_StatusTypeDef USBD_LL_Init(USBD_HandleTypeDef *pdev)
{
    /* 只设 hpcd.pData，没设 pdev->pData */
    hpcd_USB_DRD_FS.pData = pdev;
    /* ... HAL_PCD_Init ... */
}
```

后果：之后 `USBD_LL_Transmit` 等函数用 `pdev->pData` 当 PCD handle，结果是 NULL，调 HAL_PCD_EP_Transmit 立刻 hard fault。

✔ **正确**：双向绑定。

```c
hpcd_USB_DRD_FS.pData = pdev;
pdev->pData           = &hpcd_USB_DRD_FS;
```

---

### 11.11 ❌ 不响应 SET_LINE_CODING

❌ **错误**：

```c
static int8_t CDC_Control_FS(uint8_t cmd, uint8_t *pbuf, uint16_t length)
{
    return USBD_OK;   /* 全部当作不存在的命令吃掉 */
}
```

后果：Windows 大部分串口工具打开 COM 口前会先发 `SET_LINE_CODING` 设波特率，若 stall（USBD_FAIL）→ 用户看到"打开端口失败"。

✔ **正确**：保留 7 字节本地副本即可，无需真改硬件 UART。

---

### 11.12 ❌ 静态内存池忘记复位 used 标志

❌ **错误**：USB 拔出再插入触发 DeInit/Init 序列时，静态池 used 标志没清，导致第二次分配返回 NULL。

```c
void *USBD_static_malloc(uint32_t size)
{
    if (usbd_static_pool_used) return NULL;   /* 只设不清 → 重连后必失败 */
    usbd_static_pool_used = 1U;
    return usbd_static_pool;
}
```

✔ **正确**：

```c
void USBD_static_free(void *p)
{
    if (p == (void *)usbd_static_pool) {
        usbd_static_pool_used = 0U;   /* DeInit 时归还 */
    }
}
```

---

### 11.13 ❌ HAL_Init 之前用 HAL_GPIO

诊断阶段为了"最早期点亮 LED"会想直接调 `HAL_GPIO_WritePin`。但 `HAL_Init` 还没跑、`uwTick` 还没初始化、systick 还没起，而且 GPIO 端口时钟可能没开。

✔ **正确做法**：用裸寄存器，不依赖 HAL：

```c
int main(void)
{
    /* 完全不依赖 HAL，直接寄存器点亮 PA1 */
    RCC->IOPENR |= RCC_IOPENR_GPIOAEN;
    GPIOA->MODER = (GPIOA->MODER & ~(0x3U << 2)) | (0x1U << 2);
    GPIOA->BSRR  = GPIO_BSRR_BS1;

    HAL_Init();
    /* ... 后续才能用 HAL_GPIO_* ... */
}
```

---

### 11.14 ❌ STLink 烧录后忘记断电重启

`pio run -t upload` 默认配置可能让 OpenOCD 把 MCU 留在 halt 状态。如果 LED 不亮，**先做一次完整断电**（拔 USB 再插）再判断，不要一上来就怀疑代码。

```bash
# 烧录后必做：
pio run -t upload
# 拔 STLink USB → 等 2 秒 → 重新插上 → 观察现象
```

---

### 11.15 ❌ 调试时把 `USBD_LL_*` 改了但忘记同步

经常在调试 PMA 或描述符时改 `usbd_conf.c` 里的 PMA offset / dev_endpoints，**重新烧录前一定要 `pio run -t clean`**，不然链接器可能用旧的 .o 文件。

---

### 11.16 ❌ 在 main 里用 `printf("hello\n")` 之类写 USB

`stdio.h::printf` 默认走 newlib 的 `_write` syscall，stm32cube 框架里 `_write` 是空实现。要把 `printf` 重定向到 USB CDC 不仅要 retarget `_write`，还要解决"`printf` 是阻塞的"这个根本问题。

✔ **建议**：直接用 `snprintf` 写到本地 buf，然后 `CDC_Transmit_NonBlocking(buf, n)` 发出去（本工程 `?` 命令就是这套路）。

---

## 调试方法论：LED 打卡 + 二分法

这次 SYSCFG 坑能在 30 分钟内定位，**关键是 LED 打卡 + 二分法**。

### 1. 永远先做"最早期诊断信号"

在 `main()` 第一行用裸寄存器点亮一个 LED，覆盖一切可能的失败点：

```c
int main(void)
{
    RCC->IOPENR |= RCC_IOPENR_GPIOAEN;
    GPIOA->MODER = (GPIOA->MODER & ~(0x3U<<2)) | (0x1U<<2);
    GPIOA->BSRR  = GPIO_BSRR_BS1;
    /* ... */
}
```

如果连这都点不亮，问题在烧录/启动文件/向量表/复位向量/电源；不是你的应用逻辑。

### 2. 错误处理走"快闪"模式区分

```c
void Error_Handler(void)
{
    for (;;) {
        HAL_GPIO_TogglePin(LED_SYS_GPIO_Port, LED_SYS_Pin);
        for (volatile uint32_t i = 0; i < 200000U; i++) __NOP();
    }
}
```

正常 1Hz vs Error 5Hz 一眼可分。

### 3. 复杂初始化用"打卡灯"逐步定位

每过一步关键流程让 LED 短闪一下（200ms 亮 / 200ms 灭），数闪几下能定位到具体哪一步挂死。本次实战中就是用 PA2 闪 N 下定位到了 `USBD_Start` 内部。

### 4. 二分屏蔽 + 二分启用

定位"USB 通信卡死"时的二分思路：

| 步骤 | 做法 | 期望 |
|---|---|---|
| 1 | 全注释 USB → 单 LED 闪 | 验证硬件 + 烧录链路 |
| 2 | 加 USB 库链接但不调 `MX_USB_Device_Init` | 验证全局变量初始化无副作用 |
| 3 | 调用 `MX_USB_Device_Init` 4 步分别打卡 | 定位到哪个 USBD_* 挂 |
| 4 | 临时禁用 NVIC USB IRQ | 区分"主调用挂"还是"中断挂" |
| 5 | 把 `HAL_PCD_*Callback` 改空体 | 区分"PCD HAL 自己有问题"还是"应用层 callback" |

每步只改一个变量，结果异常就锁定到这一步。

---

## 上线测试 Checklist

### 编译与烧录

- [ ] `pio run` 编译干净通过，无 warning（除可忽略的 `-Wunused-parameter` 等）
- [ ] Flash 占用 < 50%，RAM 占用 < 20%（本工程 17832 / 524288，2980 / 147456）
- [ ] `pio run -t upload` 成功，**断电重启**

### 离线（不连 PC）

- [ ] PA1 1Hz 心跳闪
- [ ] PA2 熄灭

### 在线（连 PC）

- [ ] 1~2 秒内枚举完成，PC 设备管理器出现新 COM 口（VID 0483, PID 5740）
- [ ] PA2 变常亮
- [ ] `pio device monitor` 打开端口不报错
- [ ] 发任意行 `\n` 结尾，设备完整 echo `\r\n`
- [ ] 发 `?\n`，回 `CRS TRIM=0xXX SYNCOK=N ERR=N MISS=N OVF=N`
- [ ] 等 5 秒再发 `?\n`，`SYNCOK` 涨幅约 5000
- [ ] 连续高频敲键盘，PA2 可见反相闪烁
- [ ] 拔 USB 数据线，PA2 立刻熄灭，PA1 心跳不停
- [ ] 重新插上，1~2 秒内重新枚举，COM 口名（含序列号）保持一致

### 异常压测

- [ ] 发一次 64 字节以上的长行（如 100 字节），完整 echo
- [ ] 持续高速发送 1 分钟（如脚本 `for i in {1..1000}; do echo "$i" > COMx; done`），无死锁、无掉帧
- [ ] 在打开 COM 的情况下复位 MCU（按 NRST 或断电），PC 端工具能恢复连接

---

## 常见问题速查

| 现象 | 可能原因 | 排查方向 |
|---|---|---|
| LED 全黑（PA1 也不闪） | 主循环饿死 / Reset_Handler 之前挂 | 11.1 SYSCFG / 早期诊断信号 |
| PA1 5Hz 快闪 | 进了 Error_Handler | 时钟配置（HSI48 / CRS / PeriphCLK）|
| PA1 1Hz + PA2 一直熄灭 | USB 没枚举 | 数据线没接 / 主机不识别 / VID/PID 冲突 |
| PA1 1Hz + PA2 常亮，但 echo 不通 | 收发不工作 | 11.6 ReceivePacket / 11.10 pData 双向 |
| COM 口能开但卡顿/掉数据 | TX 阻塞 / 缓冲溢出 | 11.5 TX 死等 / 11.4 ISR 做业务 |
| 拔插后 COM 口名变了 | 序列号缺失 | usbd_desc.c::USBD_FS_SerialStrDescriptor |
| Win10 报"USB 设备无法识别" | 描述符错乱 / 时钟不准 | CRS 状态、PMA 不重叠、描述符长度 |
| 偶发掉线 | HSI48 偏离 | 看 `?` 输出的 ERR/MISS 是否在涨 |
| 主机识别为"未知设备"无 COM | CDC 配置描述符不全 | usbd_cdc.c 的 ConfigDesc 没改 |

---

## 参考资料

- **STM32G0B1 Reference Manual (RM0444)**：第 36 章 USB Device，第 8 章 RCC
- **STM32G0xx HAL Driver 源码**：`stm32g0xx_hal_pcd.c` / `stm32g0xx_ll_usb.c`
- **STMicroelectronics AN5305**：HSI48 oscillator and CRS basics
- **USB 2.0 Spec**：Chapter 5 (Pipes/EPs), Chapter 9 (Standard Requests)
- **USB CDC PSTN 1.20 Spec**：CDC ACM 子类（虚拟串口）
- 本工程的代码：`src/main.c`, `src/usb/*.c/.h`, `lib/STM32_USB_Device/`

---

## 一句话回顾踩坑历程

> 写了所有代码 → 烧上去 LED 全黑
> → 怀疑硬件，写最小验证（348B Flash）→ LED 亮，硬件 OK
> → 加回时钟和 HAL，LED 亮，OK
> → 加回 USB 库但不调用，LED 亮，OK
> → 调用 `MX_USB_Device_Init` 4 步打卡，发现挂在 `USBD_Start`
> → 禁用 USB IRQ 后 `USBD_Start` 能返回 → 锁定中断处理链
> → 把 `HAL_PCD_*Callback` 全改空体，仍挂 → 不在应用 callback，问题更深
> → **看 HAL_PCD_IRQHandler 源码**，发现读 `SYSCFG->IT_LINE_SR[8]`
> → 加 `__HAL_RCC_SYSCFG_CLK_ENABLE()` → 一切正常

整个过程 **没用 SWD 调试器**，纯靠 LED 二分法。下次遇到同类问题直接对号入座即可。

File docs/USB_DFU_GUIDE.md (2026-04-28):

# USB DFU 升级 - 详细参考手册

> **日常使用看简洁版** → [USB_DFU.md](USB_DFU.md)（一页纸搞定）
> 本文是详尽参考：原理、排错、所有踩坑、实现细节。
>
> 对应实现：`src/dfu.{c,h}` + `tools/dfu_upload.py`
> 对应 ROM：STM32G0B1 出厂 System Memory（地址 `0x1FFF0000`）
> 协议：USB Device Firmware Upgrade（DFU 1.1，VID:0483 PID:DF11）

## 0. TL;DR（已配置过的环境）

```powershell
pio run
python tools\dfu_upload.py .pio\build\nucleo_g0b1re\firmware.bin
```

脚本全自动：找串口 → 发 `dfu` → 等 ROM bootloader → `dfu-util` 烧 + leave → 应用回归。
不按 BOOT0、不拔插 USB、不用 STLink。

---

## 1. 第一次配置（每台 PC 配一次即可）

### 1.1 安装 dfu-util

| 系统 | 命令 |
|---|---|
| Windows | `scoop install dfu-util`（首次需先 `irm get.scoop.sh \| iex` 装 scoop） |
| Linux (Debian/Ubuntu) | `sudo apt install dfu-util` |
| macOS | `brew install dfu-util` |

> ⚠ winget 仓库里**没有** dfu-util；Windows 推荐用 scoop。

装完后**新开一个 PowerShell 窗口**让 PATH 生效，验证：

```powershell
dfu-util -V
```

应该看到 `dfu-util 0.11` 或更高。

### 1.2 安装 Python 与依赖

PlatformIO 自带一个内嵌 Python（`~/.platformio/penv/`），但它是 PIO 私有的，升级 PIO 时可能被重建。**推荐装一个独立 Python** 长期使用：

| 系统 | 命令 |
|---|---|
| Windows | `scoop install python` |
| Linux (Debian/Ubuntu) | `sudo apt install python3 python3-pip` |
| macOS | `brew install python` |

> ⚠ Windows 上不要用 Microsoft Store 的 Python "App execution alias"——它有时不能正确把 `python` 加到 PATH，导致脚本运行时报 "Python was not found"。
> 用 scoop 装的版本通过 `~\scoop\shims\python.exe` 注册，PATH 干净可靠。

装完后 **新开一个终端**，验证 + 装 pyserial：

```powershell
python --version          # 应看到 Python 3.x
pip install pyserial      # 装到独立 Python 的 site-packages
```

> 备选（不装独立 Python）：直接用 PIO 内嵌的那个跑 dfu_upload.py：
> ```powershell
> & "$HOME\.platformio\penv\Scripts\python.exe" tools\dfu_upload.py .pio\build\nucleo_g0b1re\firmware.bin
> ```
> PIO 内嵌 Python 已经自带 pyserial，能跑，但命令冗长且 PIO 升级可能丢包。

### 1.3 Windows：用 Zadig 装 WinUSB 驱动（仅一次）

Windows 默认会给 ST DFU 设备装一个 ST 私有驱动，`dfu-util` 用不了。需要用 [Zadig](https://zadig.akeo.ie/) 替换为 WinUSB 驱动。

**只对 DFU 模式的设备装一次**，不影响应用模式 CDC：

1. 让设备进入 DFU 模式：先用 STLink 烧一次本工程固件 → 串口 monitor 发 `dfu\r\n` → 设备会重枚举为 DFU 模式（VID:0483 PID:DF11）
2. 打开 Zadig：`Options → List All Devices`
3. 在下拉列表里找到 **STM32 BOOTLOADER**（注意 USB ID 必须是 `0483 DF11`，**不要选 CDC 的那个**）
4. 右侧目标驱动选 **WinUSB**（不是 libusb-win32！）
5. 点 `Replace Driver`
6. 完成后重新插一次 USB

> **不要用 Zadig 替换 CDC（VID:0483 PID:5740）的驱动**，否则正常的虚拟串口会失效，需要在设备管理器里卸载并让 Windows 重装。

Linux/macOS 不需要这步，但 Linux 下可能需要 udev 规则（见 §6 排错）。

---

## 2. 升级流程（日常用）

### 2.1 应用层在跑的状态下

```bash
python tools/dfu_upload.py .pio/build/nucleo_g0b1re/firmware.bin
```

脚本内部步骤：
1. `serial.tools.list_ports` 找到 VID:0483 PID:5740 的虚拟串口
2. 打开串口、发 `dfu\r\n`
3. 读到 `entering DFU` 响应
4. 设备 100ms 后软复位 → ROM bootloader 启动 → 重新枚举为 VID:0483 PID:DF11
5. 轮询 `dfu-util -l`，最多等 8 秒
6. `dfu-util -a 0 -s 0x08000000:leave -D firmware.bin` 烧 + leave
7. ROM 跳回 `0x08000000` → 应用启动 → CDC 重新枚举

整个过程 USB 线一直插着，不需要任何物理操作。

### 2.2 应用挂死、串口不通时（兜底）

应用如果崩溃到无法响应 `dfu` 命令：

**首选：STLink 直刷**

```bash
pio run -t upload
```

PlatformIO 默认配置 `reset_config srst_only` 即 connect-under-reset，几乎所有"看起来砖了"的情况（HardFault / 死循环 / 中断风暴 / SWD 被复用）都能强行接管。永远是最可靠的兜底——ROM bootloader 在 0x1FFF0000 ROM 区不可写，本工程也从不修改 option byte / RDP，硬件级安全。

如果 PIO 默认连不上，用 **STM32CubeProgrammer GUI** 强解：
1. ST-LINK 模式选 **"Under reset"**（不是 "Normal"）
2. Connect → Erasing & Programming → 选 `firmware.elf` → Start

**关于硬件 BOOT0**

> ⚠ STM32G0 出厂默认 `nBOOT_SEL=1`，BOOT0 **引脚不生效**，启动模式由 option byte 决定。
> 因此即便接出 BOOT0 跳线，短到 VDD 也不会进 ROM bootloader。
> 想用硬件 BOOT0 触发的话，需要先用 STLink 把 option byte `nBOOT_SEL` 改成 0；
> 但既然 STLink 都连上了，直接刷固件更省事，所以本工程不推荐这条路。

---

## 3. 内部实现要点

### 3.1 启动流程

```
上电 / 任何复位
    │
    ▼
main() 第 1 行：DFU_CheckAndJumpEarly()
    │
    ├─ 读 TAMP->BKP0R
    │     │
    │     ├─ != magic → return → 走正常应用启动 (HAL_Init / Clock / USB / ...)
    │     │
    │     └─ == magic → 清 magic、关中断、SYSCFG remap、跳 0x1FFF0000 (永不返回)
```

### 3.2 magic 为什么放 TAMP backup register

| 选项 | 软复位保留 | 上电(POR)保留 | 实现复杂度 |
|---|---|---|---|
| 普通 RAM 变量 | 是* | 否 | 低 |
| `.noinit` 段变量 | 是 | 否 | 中（要改链接脚本） |
| **TAMP_BKP0R** | **是** | **否** | **低** |
| Flash | 是 | 是（不想要） | 高 |

\* 普通 RAM 软复位保留是"未定义行为"，靠不住

TAMP backup 在 V_DD 断电时清零，避免 magic 残留导致一直进 DFU；而我们想要的"软复位时跳 DFU"恰好命中。

### 3.3 跳转代码必须做的事

| 步骤 | 为什么 |
|---|---|
| `__disable_irq()` | 防 PCD/SysTick 中断打扰 ROM |
| `SysTick->CTRL = 0` | 关 SysTick，避免 ROM 启动后 1ms 误触发我们 SysTick_Handler |
| `SYSCFG MEM_MODE=01` | 把 system memory 重映射到 0x00000000，ROM 通过此地址取 SP/PC |
| `__set_MSP(*0x1FFF0000)` | 切换到 ROM 的栈 |
| 函数指针跳 `*0x1FFF0004` | 进入 ROM Reset_Handler |

### 3.4 dfu-util 的 `:leave` 参数

```
-s 0x08000000:leave
```

`:leave` 让 ROM bootloader 烧完之后自动执行 USB DFU detach 流程，并跳到 0x08000000 应用入口。如果不加 `:leave`，烧完之后设备还停在 DFU 模式，必须手动断电或用 `dfu-util -e` 触发 detach。

---

## 4. 常见命令速查

```bash
# 查看当前所有 DFU 设备
dfu-util -l

# 不烧录，只触发 ROM bootloader leave（让设备从 DFU 跳回应用）
dfu-util -e

# 详细日志（-v 多次叠加）
dfu-util -v -v -a 0 -s 0x08000000:leave -D firmware.bin

# 直接传 .bin（不要 .hex 不要 .elf）
# PIO 编译产物路径：.pio/build/<env_name>/firmware.bin
```

---

## 5. 排错 / 已知坑

### 5.1 `Error during download get_status` + dfu-util exit 74（**假错误**）

末尾出现：

```
File downloaded successfully
Submitting leave request...
Error during download get_status
```

→ **烧录已经成功**，可以无视。

原因：ROM bootloader 收到 `:leave` 后**立即**从 USB 总线 detach 并跳应用，dfu-util 还在等最后一次 USB get_status 应答，因此报 IO 错误并以 EX_IOERR (74) 退出。

验证：观察 PA1 是否恢复 1Hz 心跳 + CDC（PID:5740）是否重新出现即可。

`tools/dfu_upload.py` 已对此做容错处理：检测到 exit 74 时会自动等 2 秒确认 DFU 设备已消失，确认后视为成功。所以这条假错误不再阻塞自动化流程。

### 5.2 Windows: `dfu-util: Cannot open DFU device 0483:df11`

→ 没装 WinUSB 驱动。返回 §1.3 用 Zadig 处理。

### 5.2 `STM32 CDC device [0483:5740] not found`

可能原因：
- 设备没插好 / Windows 还没枚举（再等 1 秒重试）
- 旧固件用了不同的 PID（修改过 `usbd_desc.c` 的 USBD_PID 时要同步改 `dfu_upload.py`）
- 设备已经在 DFU 模式（用 `--skip-trigger`）

### 5.3 `timeout: DFU device did not appear`

可能原因：
1. 应用没收到 / 没正确响应 `dfu` 命令 → 串口 monitor 看实际响应
2. ROM bootloader 启动了但 DP 上拉没起作用 → 等 2-3 秒；STM32G0 内置上拉应该没问题
3. Windows 设备管理器里有黄色感叹号 → Zadig 装驱动

### 5.4 `dfu-util: ERROR: bytes_per_hash=0`

老版本 dfu-util bug，升级到 0.11+。`winget` / `apt` 装的一般够新。

### 5.5 烧完之后 LED 不闪 / CDC 不出来

ROM bootloader `:leave` 跳应用时，向量表已经在 `0x08000000`。如果你的应用没正确设置 VTOR，会跳挂。本工程在 `system_stm32g0xx.c` 里默认正确设置 VTOR=0x08000000，无需手动处理。

如果排查不下来，用 STLink 重烧最近一次稳定固件即可恢复。

### 5.6 Linux: `Cannot open DFU device 0483:df11` (Permission denied)

写一个 udev 规则：

```bash
sudo tee /etc/udev/rules.d/99-stm32-dfu.rules <<'EOF'
SUBSYSTEMS=="usb", ATTRS{idVendor}=="0483", ATTRS{idProduct}=="df11", MODE="0666"
EOF

sudo udevadm control --reload-rules
sudo udevadm trigger
```

重新插 USB 即可。

---

## 6. Flash 是否会被破坏？

**不会**。

- ROM bootloader 在 `0x1FFF0000`（System memory，独立的 ROM 区），不可写
- 应用 Flash 在 `0x08000000`，dfu-util 写入；写入失败也只是应用区损坏，下次再写就修复
- 永远可以用 STLink 重烧（兜底）

唯一不能干的：用 dfu-util 写 option byte（除非真的要改 nBOOT_SEL 等），不熟悉的话**别动**。

---

## 7. 后续可能的扩展

| 想法 | 实现思路 |
|---|---|
| `pio run -t upload` 直接走 USB DFU | platformio.ini 加 `upload_protocol = custom` + `upload_command` 调用 `dfu_upload.py` |
| 校验固件版本（防降级 / 防误烧） | 应用 .bin 末尾写 magic + version；dfu_upload.py 烧前先比对 |
| 按按键进 DFU | GPIO 中断 → 调 `DFU_RebootToBootloader()` |
| 双 image A/B 升级 | STM32G0B1 有 dual bank 选项，但 G0B1**CB**（128KB）单 bank，不适用 |

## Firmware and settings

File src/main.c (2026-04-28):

/**
 * @file  main.c
 * @brief 应用装配层 - 启动顺序 + 主循环调度
 *
 * 本文件刻意保持精简：所有具体业务都在独立模块里实现，main.c 只负责
 *   1. 早期诊断点亮（不依赖任何库，证明 CPU 跑到 main）
 *   2. 按正确顺序调用各模块的 Init
 *   3. 主循环周期调用各模块的 Update / Service
 *
 * ┌──────────────┐
 * │ 启动序列      │
 * └──────────────┘
 *   0. DFU_CheckAndJumpEarly - 软复位 magic 命中则跳 ROM bootloader
 *   1. 寄存器级点亮 PA1     - 可视化 main 入口
 *   2. HAL_Init             - SysTick / NVIC / 默认时钟
 *   3. LED_Init             - PA1/PA2 推挽输出
 *   4. Clock_Init           - HSI16 SYSCLK + HSI48 USB + CRS
 *   5. MX_USB_Device_Init   - 启动 USB 设备栈（不阻塞）
 *   6. CLI_Init / DFU_Init  - 注册内置命令（"?" 与 "dfu"）
 *   7.（未来）Pwm_Init / FanCtl_Init / ... 在此处插入
 *
 * ┌──────────────┐
 * │ 主循环调度     │
 * └──────────────┘
 *   每一轮：
 *     - LED_Sys_Update     1Hz 心跳，证明主循环活着
 *     - LED_Usb_Update     未枚举=灭 / 枚举=亮 / 事件=反相闪
 *     - CRS_Poll           轮询 CRS 校准状态
 *     - CLI_Service        消费 USB RX，分发命令 / 默认 echo
 *     - （未来）FanCtl_Service / ProtoCol_Service ...
 *
 * 历史踩坑笔记（2026-04 排障）：
 *   STM32G0 上 USB / UCPD1 / UCPD2 共享 IRQn 28；HAL_PCD_IRQHandler 入口要读
 *   SYSCFG->IT_LINE_SR[8] 辨认是哪个外设触发。SYSCFG 时钟默认关，必须在
 *   HAL_PCD_MspInit 里 __HAL_RCC_SYSCFG_CLK_ENABLE，否则 ISR 读 0 → 立刻 return
 *   而 ISTR 标志未清 → NVIC 反复触发 → main 永久饿死，PA1/PA2 全黑。
 */

#include "stm32g0xx_hal.h"

#include "clock.h"
#include "led.h"
#include "cli.h"
#include "crs_diag.h"
#include "dfu.h"
#include "error.h"
#include "pwm.h"
#include "tach.h"
#include "fanctl.h"
#include "usb_device.h"
#include "usbd_cdc_if.h"

int main(void)
{
    /* === 阶段 -1：DFU 复位 magic 检查（必须最早，几乎零开销） ===
     * 上一轮应用如果收到 "dfu" 命令会写 magic 到 TAMP backup register
     * 然后软复位。此处复位后第一时间检查 → 命中则跳 ROM bootloader
     * （永不返回）。正常上电/复位时 magic 为 0，几条指令开销后继续走。
     */
    DFU_CheckAndJumpEarly();

    /* === 阶段 0：最早期诊断信号 ===
     * 完全不依赖 HAL/时钟，直接寄存器点亮 PA1（上电默认 HSI16 已在跑）
     *   - PA1 完全不亮  → 没跑到 main()（烧录失败 / 启动文件 / 向量表）
     *   - PA1 立刻常亮 → 已进 main()，问题在 HAL_Init 或后续配置
     *   - 后续 LED_Sys_Update 进入 1 Hz 闪烁会自然覆盖此初态
     */
    RCC->IOPENR  |= RCC_IOPENR_GPIOAEN;
    GPIOA->MODER  = (GPIOA->MODER & ~(0x3U << (1U * 2U))) | (0x1U << (1U * 2U));
    GPIOA->BSRR   = GPIO_BSRR_BS1;

    /* === 阶段 1：核心初始化 === */
    HAL_Init();
    LED_Init();
    Clock_Init();

    /* 时钟和 LED 都 OK，把早期诊断信号清掉，从此进入 1 Hz 心跳节奏 */
    LED_Sys_Set(0U);

    /* === 阶段 2：USB 设备栈启动（不阻塞，枚举由后续中断驱动） === */
    MX_USB_Device_Init();

    /* === 阶段 3：应用层模块 === */
    CLI_Init();
    DFU_Init();             /* 注册 "dfu" 命令 → 重启进 ROM bootloader */

    /* === 阶段 4：（预留）后续业务模块在此处 Init，例如：
     *    Pwm_Init();        // PWM 输出
     *    FanCtl_Init();     // 风扇 PID 控制
     *    各模块在自己的 Init 里调 CLI_RegisterHandler 注册私有命令
     */
    Pwm_Init();
    Tach_Init();
    FanCtl_Init();           /* 内部注册 set/get/kick 命令 */

    /* === 主循环：所有任务都是非阻塞的"周期 service"风格 === */
    while (1) {
        uint32_t now = HAL_GetTick();

        /* 心跳和状态指示放最前，保证即使后续 service 拖时也能维持 LED 节拍 */
        LED_Sys_Update(now);
        LED_Usb_Update(now,
                       hUsbDeviceFS.dev_state == USBD_STATE_CONFIGURED,
                       CDC_TakeEventFlag());

        /* 诊断/通信 service */
        CRS_Poll();
        CLI_Service();

        /* 未来扩展点：
         *   FanCtl_Service(now);
         *   TempSensor_Service(now);
         *   Watchdog_Refresh();
         */
        FanCtl_Service(now);
        Tach_Service(now);
    }
}

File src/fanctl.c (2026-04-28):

/**
 * @file  fanctl.c
 * @brief 风扇控制与安全仲裁（CLI 协议入口）
 *
 * 状态机（简化）：
 *   - DEFAULT：上电后尚未收到任何 host 合法消息（set/kick） -> 输出 default duty
 *   - HOST：USB 已枚举，且 host watchdog 未超时 -> 输出 host 设定 duty
 *   - SAFE：USB 未枚举 或 host watchdog 超时 -> 强制 safe duty
 *   - OVERRIDE：调试/故障兜底覆盖（优先级最高）
 *
 * Watchdog 刷新：
 *   - 任一合法的 set fan / kick 命令都会刷新 last_host_msg_ms
 *
 * 命令解析：
 *   - 输入来自 CLI 的单行字节（不含 CR/LF），本模块做大小写不敏感与空白分隔解析
 *   - 解析失败返回 err <reason>
 */

#include "fanctl.h"

#include <ctype.h>
#include <stdio.h>
#include <string.h>

#include "stm32g0xx_hal.h"

#include "cli.h"
#include "pwm.h"
#include "tach.h"
#include "usb_device.h"

/* =========================================================================== */
/* 内部常量 */
/* =========================================================================== */

#define FANCTL_LINE_MAX  128U

/* fault bits（给 get status 用，便于以后扩展） */
#define FAULT_USB_NOT_CFG   (1U << 0)
#define FAULT_HOST_WD_TO    (1U << 1)

/* =========================================================================== */
/* 内部状态 */
/* =========================================================================== */

static uint8_t  host_duty_1;
static uint8_t  host_duty_2;
static uint8_t  out_duty_1;
static uint8_t  out_duty_2;
static uint8_t  override_en;
static uint8_t  override_duty;

static uint32_t last_host_msg_ms;
static uint8_t  ever_host_seen;
static fan_src_t last_src;

/* =========================================================================== */
/* 小工具：tokenizer（不会修改原始 line；只在本地 buf 上操作） */
/* =========================================================================== */

static void to_lower_ascii(char *s)
{
    for (; *s; s++) {
        if (*s >= 'A' && *s <= 'Z') {
            *s = (char)(*s - 'A' + 'a');
        }
    }
}

static char *skip_ws(char *p)
{
    while (*p == ' ' || *p == '\t') {
        p++;
    }
    return p;
}

static char *next_tok(char **pp)
{
    char *p = skip_ws(*pp);
    if (*p == '\0') {
        *pp = p;
        return NULL;
    }
    char *t = p;
    while (*p && *p != ' ' && *p != '\t') {
        p++;
    }
    if (*p) {
        *p++ = '\0';
    }
    *pp = p;
    return t;
}

static int parse_u8(const char *s, uint8_t *out)
{
    if (!s || !*s) {
        return -1;
    }
    char *end = NULL;
    long v = strtol(s, &end, 10);
    if (end == s || *end != '\0' || v < 0 || v > 255) {
        return -1;
    }
    *out = (uint8_t)v;
    return 0;
}

static uint8_t clamp_pct(uint8_t pct)
{
    if (pct > 100U) {
        return 100U;
    }
    return pct;
}

/* =========================================================================== */
/* 仲裁逻辑 */
/* =========================================================================== */

static uint8_t usb_configured(void)
{
    return (hUsbDeviceFS.dev_state == USBD_STATE_CONFIGURED) ? 1U : 0U;
}

uint32_t FanCtl_GetHostWdLeftMs(uint32_t now_ms)
{
    uint32_t dt = (uint32_t)(now_ms - last_host_msg_ms);
    if (dt >= FAN_HOST_WD_MS) {
        return 0U;
    }
    return (FAN_HOST_WD_MS - dt);
}

fan_src_t FanCtl_GetSource(void)
{
    return last_src;
}

uint8_t FanCtl_GetDuty(uint8_t ch)
{
    if (ch == 1U) return out_duty_1;
    if (ch == 2U) return out_duty_2;
    return 0U;
}

void FanCtl_SetOverride(uint8_t enable, uint8_t duty_pct)
{
    override_en = enable ? 1U : 0U;
    override_duty = clamp_pct(duty_pct);
}

void FanCtl_Service(uint32_t now_ms)
{
    uint8_t usb_ok = usb_configured();
    uint32_t wd_left = FanCtl_GetHostWdLeftMs(now_ms);

    uint8_t tgt1 = FAN_DEFAULT_DUTY_PCT;
    uint8_t tgt2 = FAN_DEFAULT_DUTY_PCT;
    fan_src_t src = FAN_SRC_DEFAULT;

    if (override_en) {
        tgt1 = override_duty;
        tgt2 = override_duty;
        src = FAN_SRC_OVERRIDE;
    } else if (!usb_ok) {
        tgt1 = FAN_SAFE_DUTY_PCT;
        tgt2 = FAN_SAFE_DUTY_PCT;
        src = FAN_SRC_SAFE;
    } else if (ever_host_seen && wd_left == 0U) {
        tgt1 = FAN_SAFE_DUTY_PCT;
        tgt2 = FAN_SAFE_DUTY_PCT;
        src = FAN_SRC_SAFE;
    } else if (ever_host_seen) {
        tgt1 = host_duty_1;
        tgt2 = host_duty_2;
        src = FAN_SRC_HOST;
    } else {
        /* DEFAULT：保持默认档，等待主机首次消息 */
    }

    /* 写到 PWM（只有变化才写，减少总线抖动） */
    if (tgt1 != out_duty_1) {
        out_duty_1 = tgt1;
        Pwm_SetDuty(PWM_CH1, out_duty_1);
    }
    if (tgt2 != out_duty_2) {
        out_duty_2 = tgt2;
        Pwm_SetDuty(PWM_CH2, out_duty_2);
    }

    last_src = src;
}

/* =========================================================================== */
/* CLI handler */
/* =========================================================================== */

static void reply_line(const char *s)
{
    if (!s) return;
    CLI_SendBytes((const uint8_t *)s, (uint16_t)strlen(s));
}
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

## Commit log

2026-04-28 Add hardware source files for GPU USB PWM Fan Controller and update documentation
2026-04-28 Remove cloned repository after deploy completes
    After install.sh copies files to /usr/local/lib/pwm_fan, the
    temporary clone is no longer needed and is cleaned up.
2026-04-28 Add GPU temperature to board status log line for pwm-fan-status
    Include max temp and duty in the board log prefix so pwm-fan-status
    shows temperature alongside board state.
2026-04-30 misc: add RTX6000D散热模型
    [rtx6000d风扇_单_参数化_高70_喇叭.stl, rtx6000d风扇_单_参数化_高70_固定在风扇上.stl]
2026-05-05 fix: update comment in HysteresisController to clarify behavior of _last_temp
    [fan_daemon.py]
